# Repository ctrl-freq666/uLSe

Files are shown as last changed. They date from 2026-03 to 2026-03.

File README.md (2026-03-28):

# uLSe
A sound gizmo based on Arduino, Mozzi Library, Light sensors and Neopixels. A little brother of LSe. Meant as introduction to DIY electronics and instrument design.

# µ-LSe (micro Light Sequencer)

µ-LSe is a pocket-sized, Arduino-based sound device that turns light into sound.

It’s a stripped-down, workshop-friendly version of the LSe (Light Sequencer) — designed as an accessible entry point into DIY electronics, experimental instruments, and creative coding.

## What it does

* Generates light patterns using RGB LEDs
* Reads light with photo sensors
* Translates light into sound using simple algorithms (bytebeat / PWM synthesis)
* Lets you interact via knobs, sensors, and buttons

## Features

* 2x RGB LEDs
* 2x light sensors (LDRs)
* 2x buttons (mode switching)
* Potentiometer control
* Piezo / mini speaker + jack output
* Multiple sound and light modes

## Why?

The original LSe is powerful but time-consuming and expensive to build.
µ-LSe keeps the core idea — light controlling sound — but reduces it to something you can build in a couple of hours.

It’s meant to be:

* hacked
* modified
* broken
* rebuilt

## Workshops

µ-LSe was designed with workshops in mind, as a hands-on introduction to:

* Arduino
* DIY electronics
* experimental instrument design

## License

This project is licensed under GPL-3.0.

You are free to use, modify, and build upon it — but any derived work must also remain open source.

## Dependencies

* Mozzi (if using original version)
* Adafruit NeoPixel

Install via Arduino Library Manager.

## Author

Ctrl Freq
(sound artist / instrument builder / circuit bender)

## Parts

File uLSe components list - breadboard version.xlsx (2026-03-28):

 | ITEM | QTT pp | LINK? | COMMENTS
 | Breadboard | 1 | https://nl.aliexpress.com/item/1112312546.html | Standard 830 Point
 | Arduino_Nano_v3.x | 1 | https://nl.aliexpress.com/item/1005009007048978.html | Nano with 328 Processor and presoldered pins - breadboard friendly | Uno and other standard boards will also work
 | USB cable for arduino | 1 |  | type depends on arduinos we will use
 | Mini Switch Push Button 4 Pin DIP 12x12 On Off Momentary | 2 | https://th.aliexpress.com/item/1005002630939502.html?scm_id=1007.40050.354490.0&scm-url=1007.40050.354490.0 | breadboard friendly
 | RGB smart led aka neopixel - 5mm, 4 pin through hole | 2 | https://www.adafruit.com/product/1938 | WS2811 addressable pixel, diffused, but any will work |  | https://th.aliexpress.com/item/32832099662.html?curPageLogUid=8QsjzzMFBf2w
Audio out: | MiniJack audio socket | 1 | https://www.adafruit.com/product/4031
 | mini jack to large jack cable | 1 |  | for connecting to audio mixer
~~AND / OR~~ | ~~Micro Speaker or ~~ | ~~1~~ | ~~https://th.aliexpress.com/item/32953088906.html?curPageLogUid=vtx9L5dZh2Nc
 | Piezzo disc with presoldered cables | 1 | https://nl.aliexpress.com/item/1005010503757289.html?curPageLogUid=fg7AmsibL6le | 20-30mm diameter with resonator for better sound?
 | Potentiometer 10K | 2 | https://th.aliexpress.com/item/1005008570514925.html | breadboard friendly
 | LDR aka Light Dependent Resistor | 2 | https://search.brave.com/images?q=ldr&source=web | standard LDR
 | Resistors: 10K - through hole | 2 |  | standard resistor
 | Jumper Wires | 30-50 |  | various lengths and colours
 | 5V power supply - maybe students can bring them? | 1

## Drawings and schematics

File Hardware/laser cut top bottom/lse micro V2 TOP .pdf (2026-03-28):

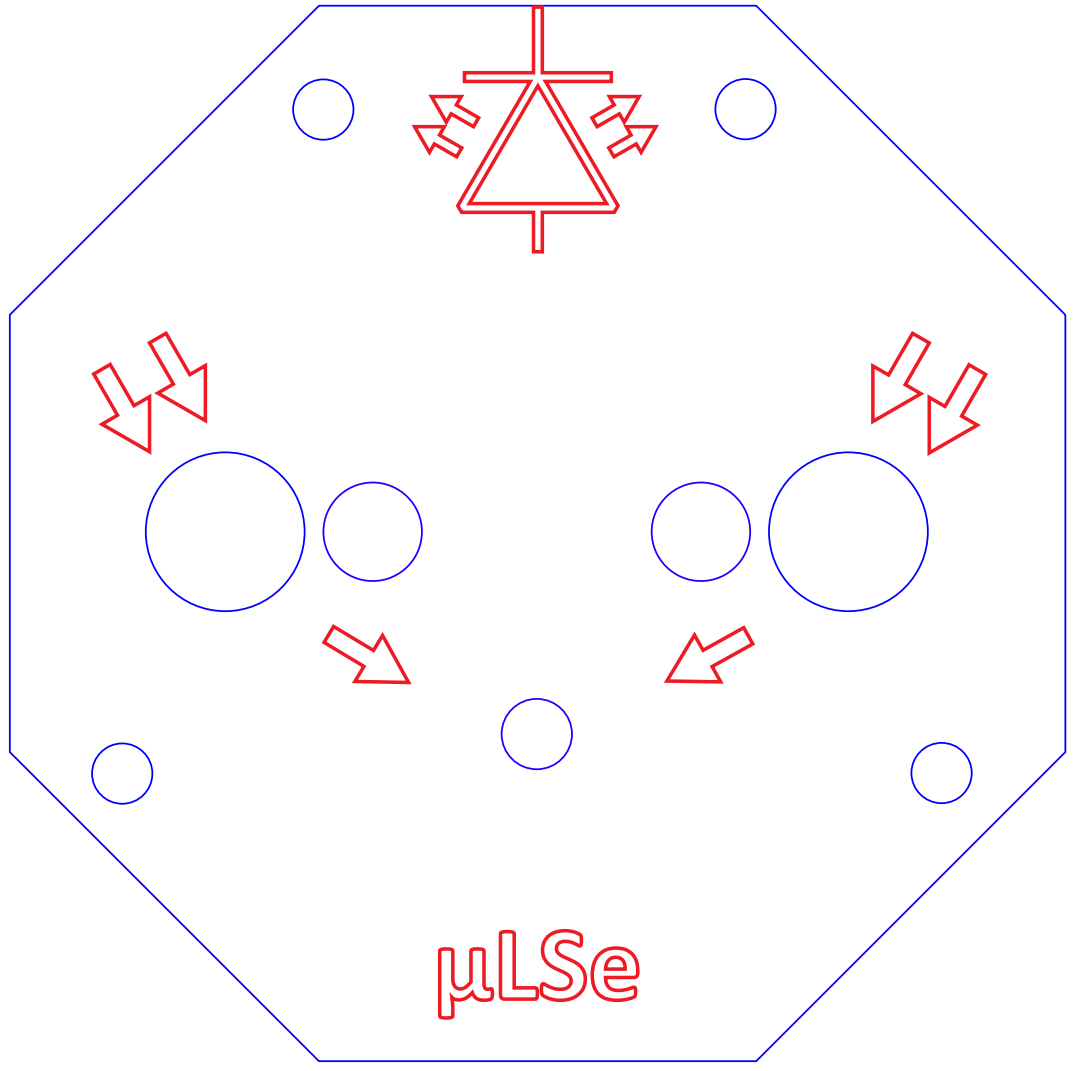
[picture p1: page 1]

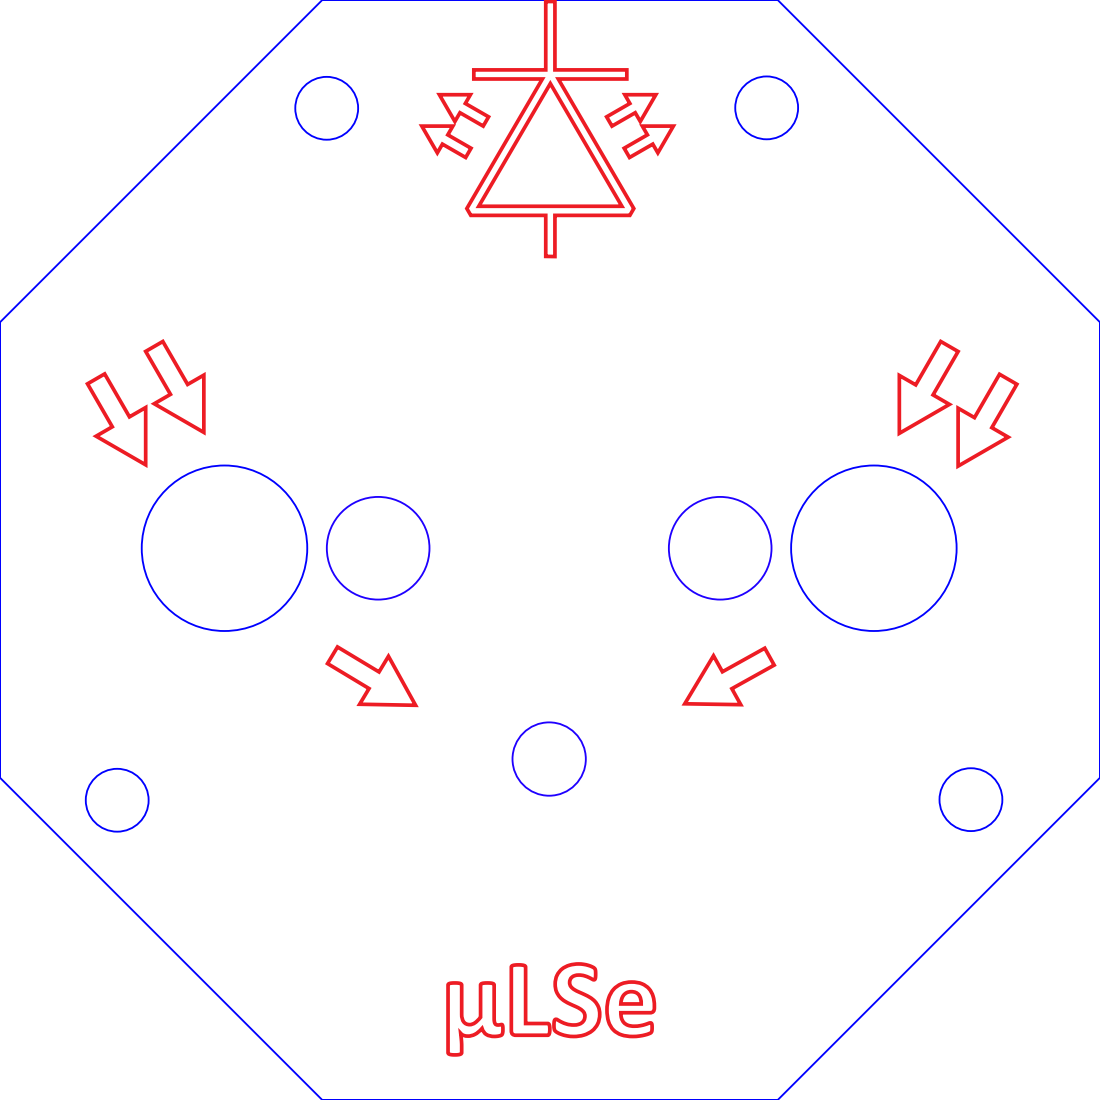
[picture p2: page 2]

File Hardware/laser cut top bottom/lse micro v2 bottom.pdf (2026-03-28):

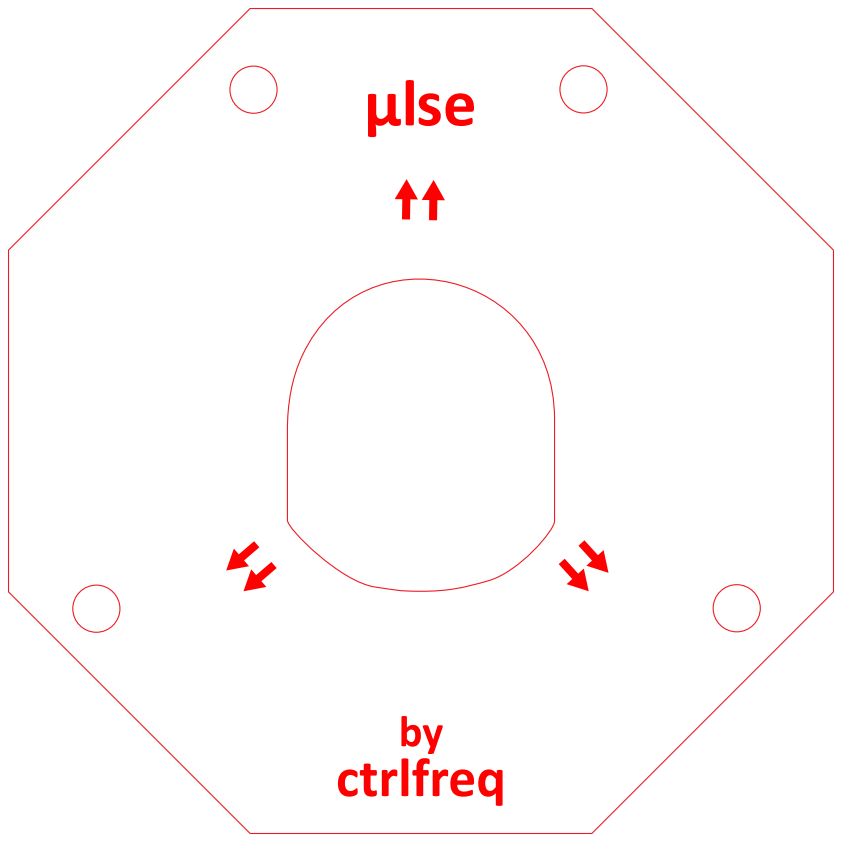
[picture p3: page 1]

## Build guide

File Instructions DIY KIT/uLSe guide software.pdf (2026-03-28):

# uLSe - building guide

## Part 2 - Software

### Intro

If you adopted the uLSe through internet or obtained it during the workshop chances are that its brain has been already programmed with the basic algorithm. In this case as soon as you power the creature with a mini USB cable with 5V power supply (from a phone charger or computer USB port) it will come to life and produce light and sound. In this case you should be able to change the patterns of lights by pressing the button on the left and by moving the left potentiometer. The right potentiometer will influence the sound. The right button has no function by default but can be programmed to do different tasks.

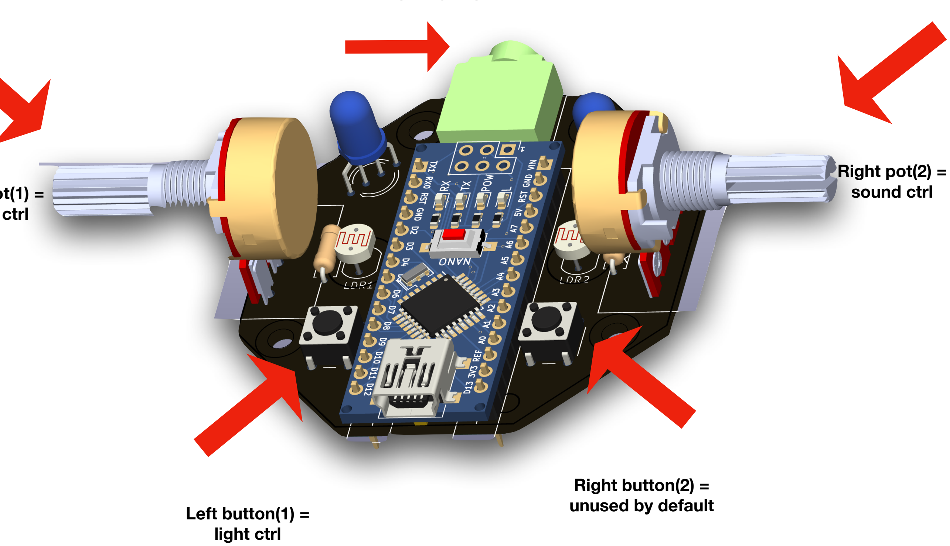
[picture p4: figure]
Left button(1) = light ctrl; Right button(2) = unused by default; Right pot(2) = sound ctrl

If the lights are changing with left button and pot than try to move them next to the ‘eyes’ of uLSe and see how it influences the sound.

Left pot(1) =
light ctrl

Audio out (mini jack)

## Reprogramming the uLSe

If your uLSe came as a DIY kit or if you would like to change the behavior of your new pet you will have to follow the steps below in order to reprogram the little creature yourself.

In this part we will (re)program our little sound and light creature so it can produce an output and react to its environment. In order to achieve it we will need:
- a computer with installed Arduino software and a USB port
- a USB cable.

We will also make us of Mozzi and NeoPixel libraries - it will be explained alter.

Download the Arduino IDE for your OS: https://www.arduino.cc/en/software/#ide. It works on Linux, Windows and Mac.

After installing the software
- Connect the uLSe to your computer with a mini USB cable.
- Start the Arduino IDE.
- select the board type (Nano) and the serial port from tools menu.

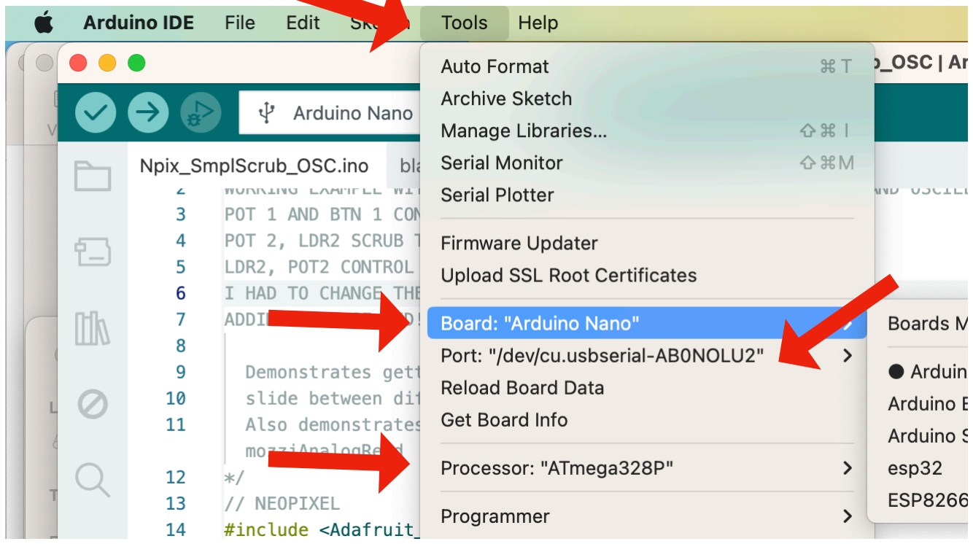
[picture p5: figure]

## Identify Serial port

In order to find your serial port name. Go to tools —> port and check the list of available ports. When you plug and unplug the Arduino a new port should show up on the list - this is your serial port.

On windows computer will serial port will be called com1 or com2 etc, on Mac it will have a name similar to the one in the picture.

If your Arduino doesn’t show up you might have to install extra drivers. Type arduino nano install drivers in your favorite internet browser followed by your operating system. This should give you instructions on how to do that.

## Install extra Libraries:

Finally we will need to install two libraries by going to tools menu —> library manager or clicking on the right side of the IDE. See picture below for reference.

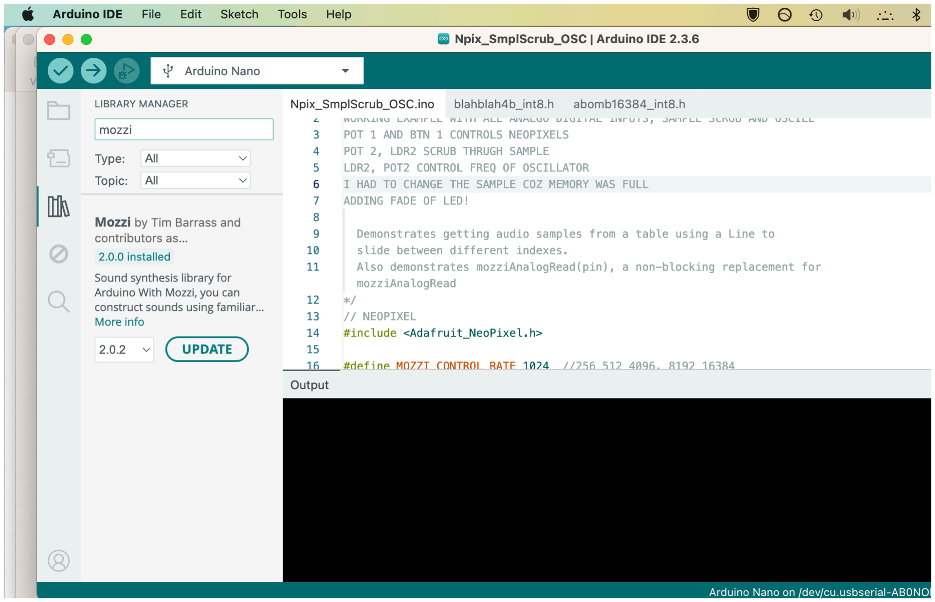
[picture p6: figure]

Install mozzi and neopixel library.

## Upload the code

We are almost there - the last step is to upload the algorithm to the Arduino.

First open the code that came with the uLSe. Then upload it by pressing the arrow button (see the picture). If everything is correct the Arduino IDE will say ‘verifying' and then ‘uploading’, after a few seconds your animal should come to life - the lights and sound should change as you press the buttons and move potentiometers and lights.

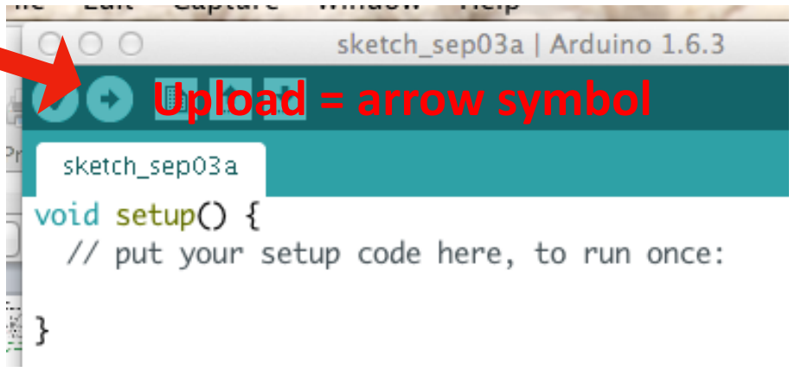
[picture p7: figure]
Upload = arrow symbol

## Congrats! You did it! Now play with it and enjoy it!

Next try to analyze the code, change some parameters and see what happens. changing the code,

Try different examples and find the one that you like best. Have fun!

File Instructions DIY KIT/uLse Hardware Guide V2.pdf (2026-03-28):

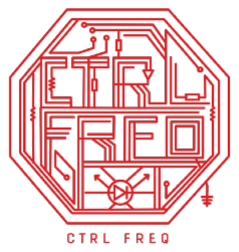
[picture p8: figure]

## µ-LSe - Assembly Instructions

### Part 1 — Hardware

### Intro

Congratulations on purchasing your new life companion! Below you will find instructions on how to assemble and bring your new pet to life.

We are truly delighted that you chose us - but let’s face it, you had no choice.
Here at CtrlFreq we share and cherish the universal values of late-stage capitalism, including but not limited to: endless exploitation of natural and human resources, tax evasion, putting profit before people, and brainwashing (aka advertising).

### Tools & Skills

If this is your first time soldering, it’s strongly recommended to follow a few tutorials, such as this one. (https://www.youtube.com/watch?v=QKbJxytERvg&themeRefresh=1)

Required tools: soldering station, wire cutter, cross screwdriver

Helpful (but optional) tools: wire stripper, hot glue gun, third hand, multimeter

When soldering, always work in a well-lit and ventilated room. We can’t be held responsible for anything. We have good lawyers, and we will win any court case. Don’t even think about it.

Losing Ctrl since 666!

## Getting Started

Soldering is like building a house - you start with the foundations and work your way up. Expensive, time-consuming, and not for everyone.

Start by identifying the top and bottom sides of the skeleton (aka PCB).

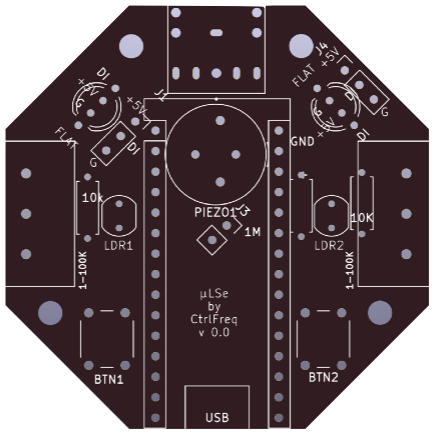
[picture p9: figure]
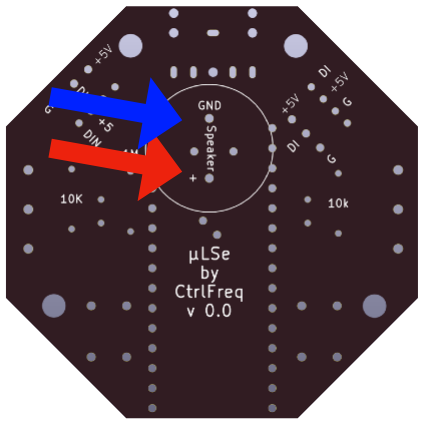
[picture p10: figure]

Step 1 — Resistors

Solder the two 10 kΩ resistors (marked as 10k) on the top side of the PCB. Polarity doesn’t matter - they can go either way. After soldering, cut the resistor legs with wire cutters so they don’t get in the way.

TOP | BOTTOM

Step 2 — Speaker Wire

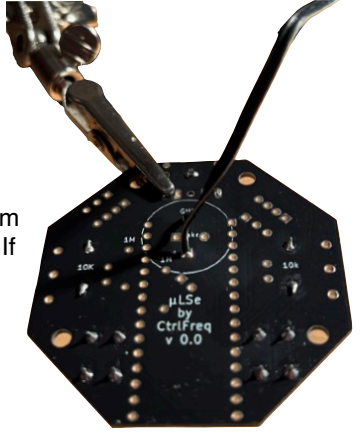
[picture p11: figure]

Solder a two-core wire (about 5 cm long) on the bottom of the PCB at the points marked Speaker GND and +. If possible, use a black wire for GND and one with a white stripe for +. We’ll use the other ends of these wires later to connect the mini speaker (or piezo) output.

Adding a piezo as an extra touch sensor input is optional. If you decide to add it, solder the 1 MΩ resistor; otherwise, you can skip this step.

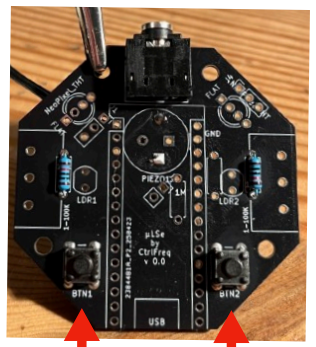
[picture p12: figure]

Step 3 — Buttons

Back on the top side, solder the two mini buttons.

A button is a digital input - it allows our creature to sense whether something is or isn’t. It only has two states: HIGH and LOW, 1 and 0, +5 V and GND.

Step 4 — Audio Jack

Solder the mini jack audio output. The footprint on the PCB shows

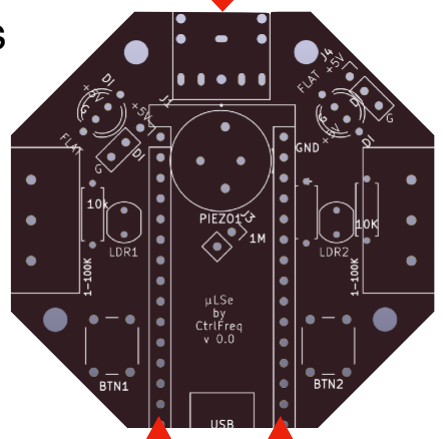
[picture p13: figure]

how to position it. The jack output, together with the speaker, forms the speaking apparatus of our little friend.

Step 5 — Arduino Headers (Brain Holders)

Add holders for the brain (Arduino) in the form of pin headers. This allows you to remove (transplant) the brain and use it for another project (patient).

If your Arduino comes without pre-soldered headers, solder them now by placing them into the female headers already attached to the PCB. Otherwise, skip this step.

TIP for soldering headers (and other multi-pin components):

1. Solder a couple of pins first - this keeps the component in place and allows you to align it.
2. Then solder every other pin - this helps prevent excessive heat buildup.
3. Finally, solder the remaining pins.

## Light Sensors = Eyes

Now comes a slightly tricky part — but fear not, there will be more!

It’s quite sad to admit, but µ-LSe suffers from a bad case of bulging eyes. Its eyes (the light sensors) protrude about 10–15 mm from their sockets — but, like aFrench bulldog,
this adds a | lot of charm.

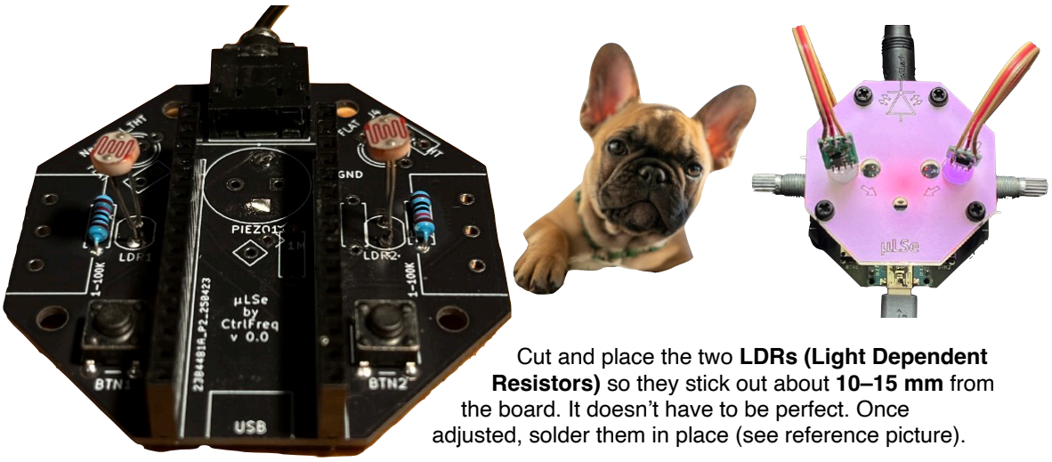
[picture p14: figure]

Cut and place the two LDRs (Light Dependent Resistors) so they stick out about 10–15 mm from the board. It doesn’t have to be perfect. Once adjusted, solder them in place (see reference picture).

Step 6 — RGB LEDs

Identify the two thin 3-core multi-cables (about 10–15 cm long, colors may vary). Strip insulation from both ends, separate each core, and tin the wires with a tiny bit of solder — it’ll make soldering and threading through holes easier.

We’re using LEDs with 3 pins: +5 V, DI, and GND. Solder one side of each cable to the 3-pin points on the PCB marked at the top left and right corners (see arrows). If there are no markings, the square pad denotes +5 V.

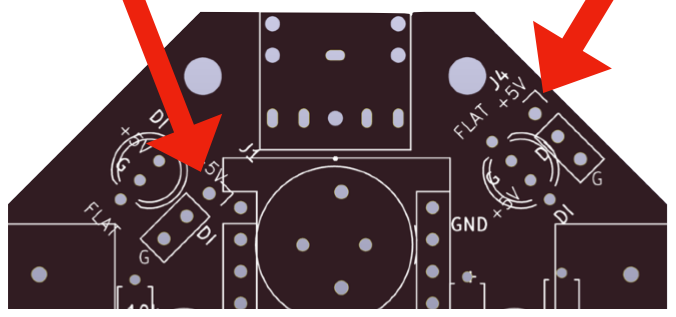
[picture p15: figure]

Now solder the other ends of the two cables to the RGB LEDs:

Make sure you solder to the correct side of the LED board - the one marked with DI. There are different LED versions, so double-check before soldering.

Arrows are pointing to the + / 5V pin

PCB SIDE | LED SIDE
+5 V (square pad) | +, 5V, 12V (depends on LED version)
DI (middle pad) | DI (make sure the side is correct)
GND (bottom pad) | G (GND, G, depends on LED version)

PCB TOP

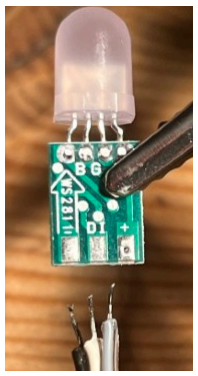
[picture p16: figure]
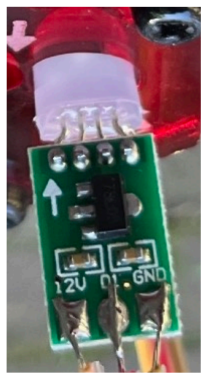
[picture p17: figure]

PCB TOP

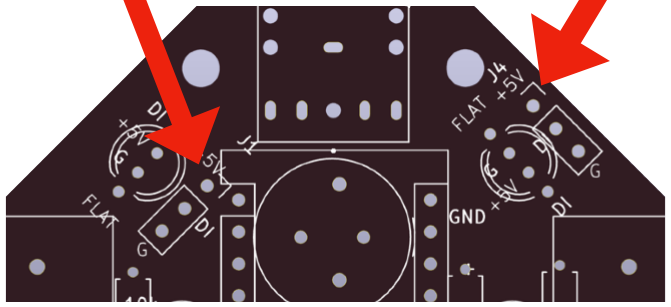
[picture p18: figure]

Step 7 - Potentiometers

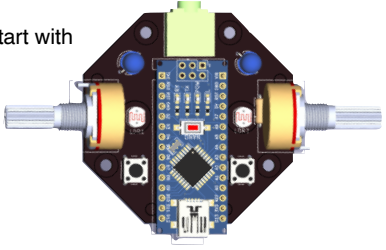
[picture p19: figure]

Solder the two potentiometers - one on each side. Start with the middle pin - it will help.

Light sensors and potentiometers are examples of
analog inputs - unlike digital ones (buttons), they
output continuous values between 0 V (GND) and 5 V.
Step 8 — Arduino

Plug the Arduino into the headers.

Congrats! You’re almost there. If you’re getting tired, take a break. :)

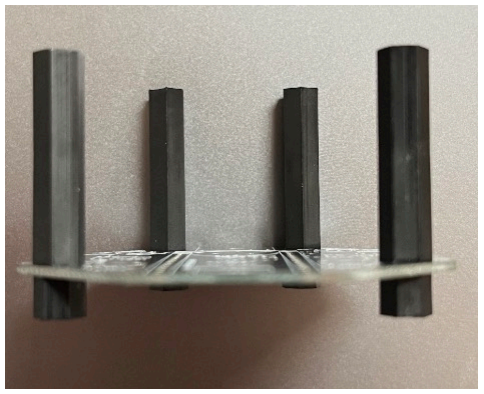
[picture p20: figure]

Step 9 - The Backbone

Identify the 4 short (5 mm) and 4 long (25 mm) hexagonal screws. Screw them together so that the short ones are at the bottom and the long ones on top — this backbone will hold all the parts together.

Whereas the PCB can be considered the skeleton, the Arduino is the brain of our little creature. In the next part, we’ll learn how to reprogram (brainwash) it.

Step 10 - Skeleton & Body

Identify the top and bottom (head and toes) of the skeleton. Make sure the speaker cable we soldered earlier goes through the hole in the bottom. Then solder the speaker from the top, as shown in the picture - otherwise, it won’t fit.

You can also replace the speaker with a piezo element — it’s a bit easier to attach to the bottom.

Use a hot glue gun or another adhesive to attach the speaker.

Be quick or be gone!

Top | Bottom

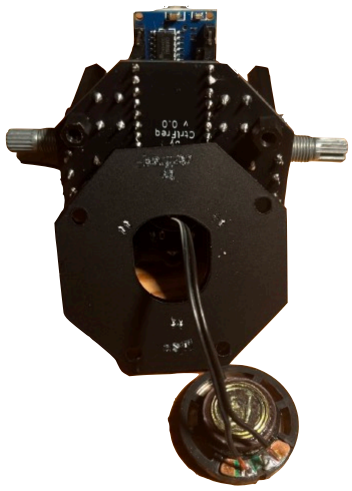
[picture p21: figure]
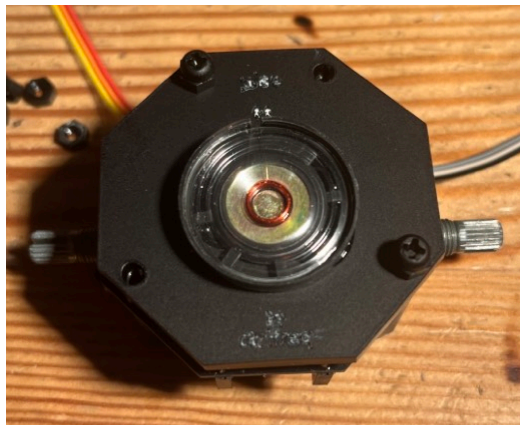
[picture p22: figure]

Step 11 - Final Assembly

Attach the top and bottom of µ-LSe with the 8 small screws. Your complete µ-LSe should now look more or less like this. If that’s the case - Well done!!!

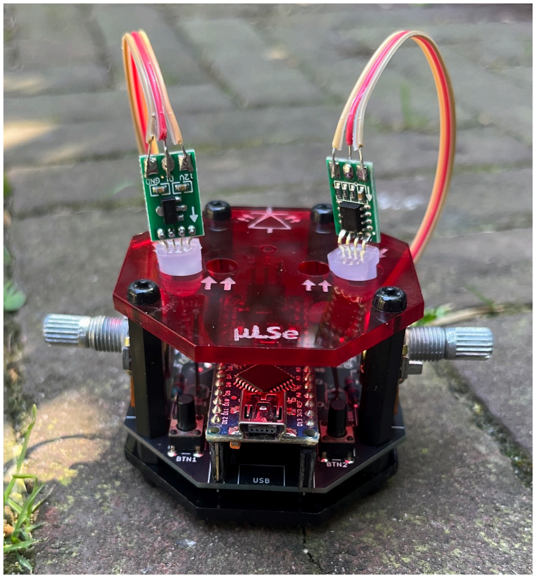
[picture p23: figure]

In the next part, we’ll upload the code to the Arduino board. That’s when your new companion will truly come to life.

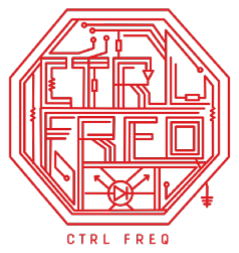
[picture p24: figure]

Losing Ctrl since 666!

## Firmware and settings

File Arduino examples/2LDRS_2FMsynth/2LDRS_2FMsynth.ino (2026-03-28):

/*
  Example using 2 light dependent resistors (LDRs) to change
  FM synthesis parameters, and a knob for fundamental frequency,
  using Mozzi sonification library.

  Demonstrates analog input, audio and control oscillators, phase modulation
  and smoothing a control signal at audio rate to avoid clicks.
  Also demonstrates AutoMap, which maps unpredictable inputs to a set range.

*/

// NEOPIXEL INIT
#include <Adafruit_NeoPixel.h>
#define NEOPIXEL_PIN1 6  // Neopixel data pin
#define NEOPIXEL_PIN2 7  // Neopixel data pin
#define NUM_PIXELS 1     // Number of Neopixels

// AUDIO LIBRARY INIT
#define MOZZI_CONTROL_RATE 512
#include <Mozzi.h>
#include <Oscil.h>                             // oscillator
#define MOZZI_ANALOG_READ_RESOLUTION 10 // code below assumes readings to be in 
#include <tables/cos2048_int8.h> // table for Oscils to play
#include <Smooth.h>
#include <AutoMap.h> // maps unpredictable inputs to a range

const char POT_LED_PIN = 0;    // knob analog pin 0 - CONTRL LEDS
const char POT_AUDIO_PIN = 1;  // analog pin 1 knob for audio control
const char LDR1_PIN = 3;       // set the input for the LDR to analog pin 2
const char LDR2_PIN = 2;       // set the input for the LDR to analog pin 3
const char BUTTON_PIN = 2;     // set the DIGITAL input pin for the BTN
const char BUTTON_PIN2 = 3;    // set the DIGITAL input pin for the BTN

// Declare our NeoPixel strip object:
Adafruit_NeoPixel strip1(NUM_PIXELS, NEOPIXEL_PIN1, NEO_GRB + NEO_KHZ800);
Adafruit_NeoPixel strip2(NUM_PIXELS, NEOPIXEL_PIN2, NEO_GRB + NEO_KHZ800);

// BUTTON FOR MODE CHANGING
int buttonState = HIGH;
int lastButtonState = HIGH;
int modeCounter = 0;                 // Mode counter for cycling through modes
unsigned long lastDebounceTime = 0;  // Time for debounce
unsigned long debounceDelay = 50;    // Debounce delay

// Blinking variables NO DELAY
unsigned long previousMillis = 0;
int blinkInterval = 40;  // Default blink interval
bool ledState = false;   // Track LED on/off state

// var to know the state of button
bool pressed = false;
bool btnVal2;
// var for random clock led
unsigned long lastRandomBlink = 0;
unsigned long randomInterval = 500;
bool randomLedState = false;

int freqOffset;
int freqOff2;
int frequency1;  // value for oscilator frequency
int frequency2;  // value for oscilator frequency

int fadeValue;  // value for fading leds

// desired carrier frequency max and min, for AutoMap
const int MIN_CARRIER_FREQ = 22;
const int MAX_CARRIER_FREQ = 440;

// desired intensity max and min, for AutoMap, note they're inverted for reverse dynamics
const int MIN_INTENSITY = 700;
const int MAX_INTENSITY = 10;

// desired mod speed max and min, for AutoMap, note they're inverted for reverse dynamics
const int MIN_MOD_SPEED = 10000;
const int MAX_MOD_SPEED = 1;

AutoMap kMapCarrierFreq(0,1023,MIN_CARRIER_FREQ,MAX_CARRIER_FREQ);
AutoMap kMapIntensity(0,1023,MIN_INTENSITY,MAX_INTENSITY);
AutoMap kMapModSpeed(0,1023,MIN_MOD_SPEED,MAX_MOD_SPEED);

Oscil<COS2048_NUM_CELLS, MOZZI_AUDIO_RATE> aCarrier(COS2048_DATA);
Oscil<COS2048_NUM_CELLS, MOZZI_AUDIO_RATE> aModulator(COS2048_DATA);
Oscil<COS2048_NUM_CELLS, MOZZI_CONTROL_RATE> kIntensityMod(COS2048_DATA);

int mod_ratio = 5; // brightness (harmonics)
long fm_intensity; // carries control info from updateControl to updateAudio

// smoothing for intensity to remove clicks on transitions
float smoothness = 0.95f;
Smooth <long> aSmoothIntensity(smoothness);


void setup(){
  //Serial.begin(9600); // for Teensy 3.1, beware printout can cause glitches
 // Serial.begin(115200); // set up the Serial output so we can look at the piezo values // set up the Serial output so we can look at the light level

  // BUTTON AS INPUT PULLUP
  pinMode(BUTTON_PIN, INPUT_PULLUP);
  pinMode(BUTTON_PIN2, INPUT_PULLUP);

  // INITALIZE LED NEOPIXEL
  strip1.setBrightness(50);  // Set BRIGHTNESS to about 1/5 (max = 255)
  strip2.setBrightness(50);   // Set BRIGHTNESS to about 1/5 (max = 255)

  strip1.begin();
  strip2.begin();
  strip1.show();  // Start with LEDs off
  strip2.show();  // Start with LEDs off


  startMozzi(); // :))
}


void updateControl(){


  //read the 1st button
  handleButtonPress();  // function to change button states
  // read analog ins

  int potValue = mozziAnalogRead<10>(POT_LED_PIN);  // 10bit value is 0-1023

  // read the knob
  int knob_value = mozziAnalogRead(POT_AUDIO_PIN); // value is 0-1023

  // map the knob to carrier frequency
  int carrier_freq = kMapCarrierFreq(knob_value);

  //calculate the modulation frequency to stay in ratio
  int mod_freq = carrier_freq * mod_ratio;

  // set the FM oscillator frequencies
  aCarrier.setFreq(carrier_freq);
  aModulator.setFreq(mod_freq);

  // read the light dependent resistor on the width Analog input pin
  int LDR1_value= mozziAnalogRead(LDR1_PIN); // value is 0-1023
  // print the value to the Serial monitor for debugging
  // Serial.print("LDR1 = ");
  // Serial.print(LDR1_value);
  // Serial.print("\t"); // prints a tab

  int LDR1_calibrated = kMapIntensity(LDR1_value);
  // Serial.print("LDR1_calibrated = ");
  // Serial.print(LDR1_calibrated);
  // Serial.print("\t"); // prints a tab

 // calculate the fm_intensity
  fm_intensity = ((long)LDR1_calibrated * (kIntensityMod.next()+128))>>8; // shift back to range after 8 bit multiply
  // Serial.print("fm_intensity = ");
  // Serial.print(fm_intensity);
  // Serial.print("\t"); // prints a tab

  // read the light dependent resistor on the speed Analog input pin
  int LDR2_value= mozziAnalogRead(LDR2_PIN); // value is 0-1023
  // Serial.print("LDR2 = ");
  // Serial.print(LDR2_value);
  // Serial.print("\t"); // prints a tab

  // use a float here for low frequencies
  float mod_speed = (float)kMapModSpeed(LDR2_value)/1000;
  // Serial.print("   mod_speed = ");
  // Serial.print(mod_speed);
  kIntensityMod.setFreq(mod_speed);

  // Serial.println(); // finally, print a carraige return for the next line of debugging info


  switch (modeCounter) {
    case 0:                                             // Blinking mode (fixed!) - inversed leds
      blinkInterval = map(potValue, 0, 1023, 10, 500);  // Blink speed

      if (millis() - previousMillis >= blinkInterval) {
        previousMillis = millis();
        ledState = !ledState;  // Toggle LED state

        if (ledState) {
          strip1.fill(strip1.Color(255, 0, 0));  // ON
          strip2.clear();                        // OFF (turn off all LEDs)

        } else {
          strip1.clear();                        // OFF (turn off all LEDs)
          strip2.fill(strip2.Color(255, 0, 0));  // ON
        }
        strip1.show();
        strip2.show();
      }
      break;

    case 1:                                             // Blinking mode (fixed!)
      blinkInterval = map(potValue, 0, 1023, 1, 1500);  // Blink speed

      if (millis() - previousMillis >= blinkInterval) {
        previousMillis = millis();
        ledState = !ledState;  // Toggle LED state

        if (ledState) {
          strip1.fill(strip1.Color(0, 255, 0));  // ON
          strip2.clear();                        //OFF (turn off al LEDs
        } else {
          strip1.clear();                        // OFF (turn off all LEDs)
          strip2.fill(strip2.Color(0, 255, 0));  // ON
        }
        strip1.show();
        strip2.show();
      }
      break;

    case 2:                                               // Blinking mode (fixed!)
      blinkInterval = map(potValue, 0, 1023, 100, 5000);  // Blink speed

      if (millis() - previousMillis >= blinkInterval) {
        previousMillis = millis();
        ledState = !ledState;  // Toggle LED state

        if (ledState) {
          strip1.fill(strip1.Color(0, 0, 255));  // ON
          strip2.clear();                        // OFF (turn off all LEDs)
        } else {
          strip1.clear();                        // OFF (turn off all LEDs)
          strip2.fill(strip2.Color(0, 0, 255));  // ON
        }
        strip1.show();
        strip2.show();
      }
      break;

    case 3:                                            // Blinking mode (fixed!)
      blinkInterval = map(potValue, 0, 1023, 1, 500);  // Blink speed

      if (millis() - previousMillis >= blinkInterval) {
        previousMillis = millis();
        ledState = !ledState;  // Toggle LED state

        if (ledState) {
          strip1.fill(strip1.Color(255, 255, 255));  // ON
          strip2.fill(strip1.Color(255, 255, 255));  // ON
        } else {
          strip1.clear();  // OFF (turn off all LEDs)
          strip2.clear();  // OFF (turn off all LEDs)
        }
        strip1.show();
        strip2.show();
      }
      break;

    case 4:  // Random color mode with 1 led going off

      blinkInterval = map(potValue, 0, 1023, 1, 1000);  // Blink speed
      if (millis() - previousMillis >= blinkInterval) {
        previousMillis = millis();
        ledState = !ledState;  // Toggle LED state
        int r = random(0, 256);
        int g = random(0, 256);
        int b = random(0, 256);

        if (ledState) {
          strip1.fill(strip1.Color(r, g, b));  // ON
          strip2.clear();
        }

        else {
          strip1.clear();                      // OFF (turn off all LEDs)
          strip2.fill(strip2.Color(r, g, b));  // ON
        }
        strip1.show();
        strip2.show();
      }
      break;

    case 5:  // Fade in/out mode

      blinkInterval = map(potValue, 0, 1024, 1, 15);  // Blink speed

      static uint8_t brightness = 0;
      static bool fadingUp = true;

      if (millis() - previousMillis >= blinkInterval) {
        previousMillis = millis();

        if (fadingUp) {
          brightness += 15;
          if (brightness >= 255) fadingUp = false;
        } else {
          brightness -= 15;
          if (brightness <= 0) fadingUp = true;
        }
        // strip.setBrightness(brightness);
        strip1.fill(strip1.Color(0, brightness, 0));
        strip2.fill(strip2.Color(255 - brightness, 0, 255 - brightness));
        strip1.show();
        strip2.show();
      }
      break;

    case 6:  // Fade in/out mode

      blinkInterval = map(potValue, 0, 1024, 1, 250);  // Blink speed
      static uint8_t brightness2 = 0;
      static bool fadingUp2 = true;

      if (millis() - previousMillis >= blinkInterval) {
        previousMillis = millis();

        if (fadingUp2) {
          brightness2 += 25;
          if (brightness2 >= 255) fadingUp2 = false;
        } else {
          brightness2 -= 25;
          if (brightness2 <= 0) fadingUp2 = true;
        }
        strip1.fill(strip1.Color(0, brightness2, 0));
        strip2.fill(strip2.Color(255 - brightness2, 0, 255 - brightness2));
        strip1.show();
        strip2.show();
      }
      break;

    case 7:  // Random color mode
      static unsigned long lastColorChange = 0;
      int randomSpeed = map(potValue, 0, 1023, 100, 2000);  // 100ms–2s

      if (millis() - lastColorChange >= randomSpeed) {
        lastColorChange = millis();

        int r = random(0, 256);
        int g = random(0, 256);
        int b = random(0, 256);
        int r2 = random(0, 256);
        int g2 = random(0, 256);
        int b2 = random(0, 256);

        strip1.fill(strip1.Color(r, g, b));
        strip2.fill(strip2.Color(r2, g2, b2));
        strip1.show();
        strip2.show();
      }
      break;

    case 8:  // Random time mode // Random interval blink mode
      if (millis() - lastRandomBlink >= randomInterval) {
        lastRandomBlink = millis();
        randomLedState = !randomLedState;

        if (randomLedState) {
          strip1.fill(strip1.Color(255, 0, 0));  // Example ON color
          strip2.clear();
        } else {
          strip1.clear();
          strip2.fill(strip2.Color(0, 0, 255));  // Example OFF color
        }

        strip1.show();
        strip2.show();

        // Now update the interval AFTER the blink occurred
        randomInterval = random(100, 2000);  // Set a new interval for next change
      }
      break;
  }
}


AudioOutput updateAudio(){
  long modulation = aSmoothIntensity.next(fm_intensity) * aModulator.next();
  return MonoOutput::from8Bit(aCarrier.phMod(modulation));
}

void loop(){
  audioHook();
}


void handleButtonPress() {
  int reading = digitalRead(BUTTON_PIN);

  if (reading != lastButtonState) {
    lastDebounceTime = millis();
  }

  if ((millis() - lastDebounceTime) > debounceDelay) {
    if (reading != buttonState) {
      buttonState = reading;
      if (buttonState == LOW) {  // Button pressed
        modeCounter++;
        if (modeCounter > 8) {
          modeCounter = 0;
        }
      }
    }
  }
  lastButtonState = reading;
}
